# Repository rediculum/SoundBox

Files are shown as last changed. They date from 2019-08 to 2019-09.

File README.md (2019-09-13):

# SoundBox
Sound box like a board to launch samples stored as 8bit full-rate (32000) mono WAV files named from 1.WAV to 8.WAV (16.WAV) on a SD card with arcade buttons using a multiplexer
## Pinout
### SD Card > Arduino pinout:
```
SCK  (5) -> Pin 13 must be!
CS (1)   -> Pin 10 (Chip select)
MOSI (2) -> Pin 11 must be!
MISO (7) -> Pin 12 must be!
```
### Speaker -> Arduino pinout:
```
Speaker (sound) -> Pin 9 and GND
```
### Multiplexer > Arduino pinout:
```
S0 -> Pin 2
S1 -> Pin 3
S2 -> Pin 4
S3 -> Pin 5 if you have a CD74HC4067 mux and provide 16 arcade buttons
SIG (Z or A) -> Pin A0
SIG (Z or A) -> Pin 6 if you have a 2nd mux for 5V luminated buttons
```
### Multiplexer -> Arcade buttons / leds:
```
A0 -> Button 1
..
A7 -> Button 8
..
A15 -> Button 16
```
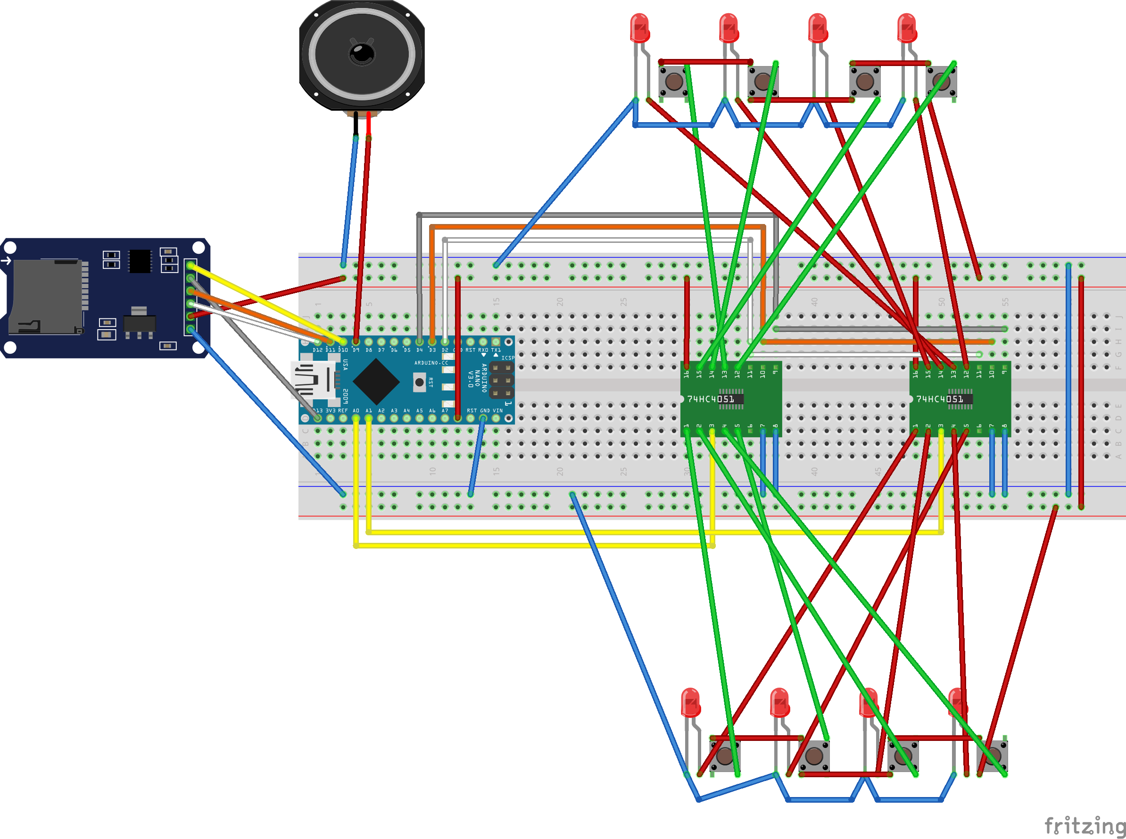
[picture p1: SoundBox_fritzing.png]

## References and used libraries
TMRpcm library for audio playback from SD card
https://github.com/TMRh20/TMRpcm or install it from Arduino IDE Lib Manager

How to deal with mux and demux
https://learn.sparkfun.com/tutorials/multiplexer-breakout-hookup-guide/all

## Convert audio to WAV with sox
This sox command will convert an MP3 file into 8bit 32k rate mono wave file.
```
sox audiofile.mp3 --norm -b8 -r32000 -c1 1.WAV
```
You may install the *libsox-fmt-mp3* package to support MP3 convertion.

## Enclosure printing
Refer to Thingiverse.com for STL download or use the Customizer to make your own case
https://www.thingiverse.com/thing:3830885
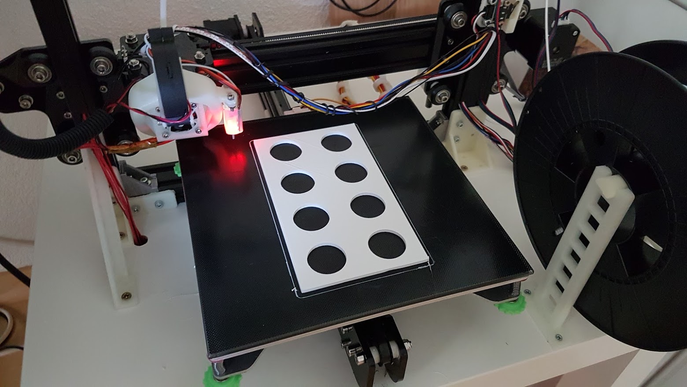
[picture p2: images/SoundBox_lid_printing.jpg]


## Pictures
### Prototype connection with jumper wires and bread board
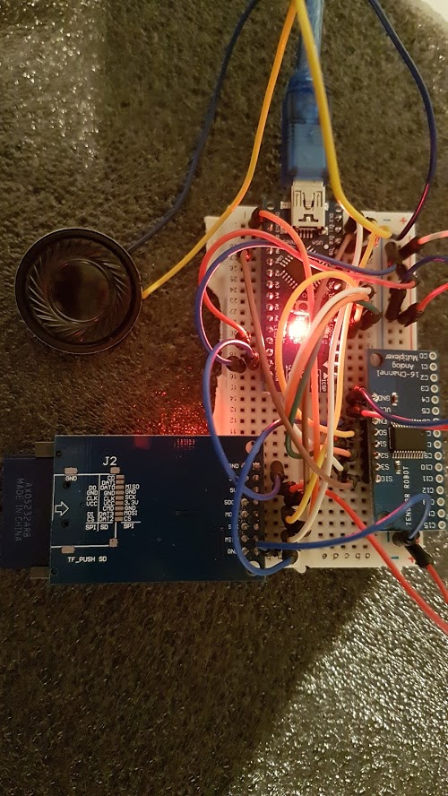
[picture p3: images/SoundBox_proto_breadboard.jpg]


### Final assembly with dupont cables and soldered wires
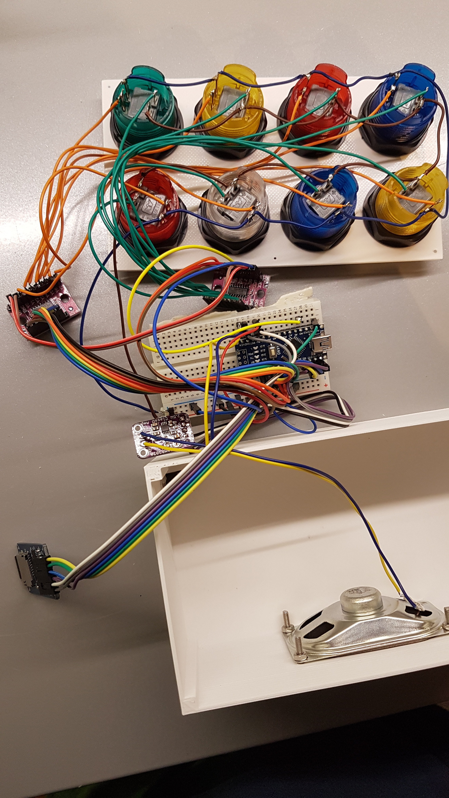
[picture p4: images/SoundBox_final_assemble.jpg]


### Demo video
(https://youtu.be/nFHPtpK2-tA)

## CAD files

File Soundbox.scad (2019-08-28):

Render = "entire"; // [body:Case,lid:Lid,entire:Entire]

screw_cones = true; // [true:Yes,false:No]
wall_thickness=1.5;
pillar_thickness_factor=4;
lid_thickness=3;
floor_thickness=8;
wall_height=70;
wall_width=90;
wall_length=160;
button_diameter=28; // [28:M28,24:M24]
buttons_per_row=4;
button_rows=2;

buttonSpace=wall_length/buttons_per_row;

module case() {
    translate([0,0,0])
        cube([wall_width,wall_thickness,wall_height]);
        cube([wall_thickness,wall_length,wall_height]);
        cube([wall_width,wall_length,floor_thickness]); // floor

    translate([0,wall_length,0])
        cube([wall_width,wall_thickness,wall_height]);

    translate([wall_width,0,0])
        cube([wall_thickness,wall_length+wall_thickness,wall_height]);

    // Pillars
        translate([wall_thickness,wall_thickness,0])
            cube([wall_thickness*pillar_thickness_factor,wall_thickness*pillar_thickness_factor,wall_height]);
        translate([wall_width-pillar_thickness_factor-wall_thickness,wall_thickness,0])
            cube([wall_thickness*pillar_thickness_factor,wall_thickness*pillar_thickness_factor,wall_height]);
        translate([wall_thickness,wall_length/2-pillar_thickness_factor/2,0])
            cube([wall_thickness*pillar_thickness_factor,wall_thickness*pillar_thickness_factor,wall_height]);
        translate([wall_width-pillar_thickness_factor-wall_thickness,wall_length/2-pillar_thickness_factor/2,0])
            cube([wall_thickness*pillar_thickness_factor,wall_thickness*pillar_thickness_factor,wall_height]);
        translate([wall_thickness,wall_length-pillar_thickness_factor-wall_thickness,0])
            cube([wall_thickness*pillar_thickness_factor,wall_thickness*pillar_thickness_factor,wall_height]);
        translate([wall_width-pillar_thickness_factor-wall_thickness,wall_length-pillar_thickness_factor-wall_thickness,0])
            cube([wall_thickness*pillar_thickness_factor,wall_thickness*pillar_thickness_factor,wall_height]);


};

module lid() {
    difference() {
        translate([0,0,wall_height]) cube([wall_width+wall_thickness,wall_length+wall_thickness,lid_thickness]); // lid
        for ( r = [1:2:3] ) {        
            for ( h = [0:buttons_per_row-1] ) {
               translate ([wall_width/4*r+wall_thickness/2,buttonSpace*h+wall_thickness/2+buttonSpace/2,wall_height]) cylinder(lid_thickness*2, button_diameter/2,button_diameter/2);
            };
        };
        // Screw cones
        if (screw_cones) {
            translate([wall_thickness+pillar_thickness_factor/2,wall_thickness+pillar_thickness_factor/2,wall_height])
                cylinder($fn=20,pillar_thickness_factor,pillar_thickness_factor/6,lid_thickness);
            translate([wall_width-pillar_thickness_factor+pillar_thickness_factor/2,wall_thickness+pillar_thickness_factor/2,wall_height])
                cylinder($fn=20,pillar_thickness_factor,pillar_thickness_factor/6,lid_thickness);
            translate([wall_thickness+pillar_thickness_factor/2,wall_length/2,wall_height])
                cylinder($fn=20,pillar_thickness_factor,pillar_thickness_factor/6,lid_thickness);
            translate([wall_width-pillar_thickness_factor/2,wall_length/2+wall_thickness,wall_height])
                cylinder($fn=20,pillar_thickness_factor,pillar_thickness_factor/6,lid_thickness);
            translate([wall_thickness+pillar_thickness_factor/2,wall_length-pillar_thickness_factor/2,wall_height])
                cylinder($fn=20,pillar_thickness_factor,pillar_thickness_factor/6,lid_thickness);
            translate([wall_width-pillar_thickness_factor/2,wall_length-pillar_thickness_factor/2,wall_height])
                cylinder($fn=20,pillar_thickness_factor,pillar_thickness_factor/6,lid_thickness);
        };
    };
};
 
if ((Render=="body") || (Render=="entire"))  case();
if ((Render=="lid") || (Render=="entire")) lid();

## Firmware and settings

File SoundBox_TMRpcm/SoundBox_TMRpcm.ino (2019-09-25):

/*
===========================================================================
Sound Box 1.0 TMRpcm version
by ReDiculum (Aug - Sep 2019)
-------------------------------
Sound box like a board to launch samples stored as 
8bit full-rate (62500) mono WAV files named from
01.WAV to 08.WAV, 11.WAV to 18.WAV, 21.WAV to 28.WAV, ... 
on a SD card with arcade buttons using a multiplexer

https://github.com/rediculum/SoundBox

SD Card > Arduino pinout:

SCK  (5) -> Pin 13 must be!
CS (1)   -> Pin 10 (Chip select)
MOSI (2) -> Pin 11 must be!
MISO (7) -> Pin 12 must be!

Speaker (sound) -> Pin 9 and GND

Potentiometer -> Pin A1

Multiplexer > Arduino pinout:
S0 -> Pin 2
S1 -> Pin 3
S2 -> Pin 4
SIG -> Pin A0 // Z of the button switch mux
SIG -> Pin 6 // Z of the button led mux if you use 5V luminated buttons

===========================================================================
References:

TMRpcm library for audio playback from SD card
https://github.com/TMRh20/TMRpcm or install it from Arduino IDE Lib Manager

How to deal with mux and demux
https://learn.sparkfun.com/tutorials/multiplexer-breakout-hookup-guide/all

===========================================================================
=== Begin of CONFIGURATION ===
*/

// Pin assignment
#define SPEAKER_PIN 9
#define SD_CHIPSELECT_PIN 10
#define Z_SWITCH_PIN A0
#define Z_LED_PIN 6
#define BUTTONS 8 // Amount of acrade buttons
#define POTI A1

// Define your S-pins from your multiplexer here. 
const byte selectPins[] = {2, 3, 4};

// Do you use a 2nd multiplexer for the button LEDs?
bool led = false;
bool fade = true; // only works with analog Z on mux

/*
===========================================================================
=== End of CONFIGURATION ===
*/

#include <SD.h>
#include <TMRpcm.h>
#include <SPI.h>

byte s_pins = sizeof(selectPins);
byte brightness = 0;
bool increment = true;

TMRpcm SdPlay;
  
void setup() {
  Serial.begin(9600); // Set console to 57600 baud
  Serial.println("=== SoundBox based on TMRpcm ===");      

  for (int i=0; i<s_pins; i++)
  {
    pinMode(selectPins[i], OUTPUT);
    digitalWrite(selectPins[i], HIGH);
  }
  
  if (led) {
    pinMode(Z_LED_PIN, OUTPUT);

    for (byte button=0; button<BUTTONS; button++)  {
      for (byte i=0; i<s_pins; i++) {
        digitalWrite(selectPins[i], button & (1<<i)?HIGH:LOW);
      }
      digitalWrite(Z_LED_PIN, HIGH);
      delay(100);
      digitalWrite(Z_LED_PIN, LOW);
    }
  }

  // Set Chip Select Pin
  SdPlay.speakerPin = SPEAKER_PIN;
  // Initialize SD Card with library SimpleSDAudio
  if (!SD.begin(SD_CHIPSELECT_PIN)) {
    tone(SPEAKER_PIN,100); delay(250); noTone(SPEAKER_PIN); delay(400);
    tone(SPEAKER_PIN,80); delay(600); noTone(SPEAKER_PIN);
    Serial.println("Error initializing SD Card");
  } else {
    Serial.println("SD Card initialized");
  }
}

void loop(void) { 
  // Read the poti value to get the decimal offset of the filename
  byte potival = map(analogRead(POTI),0,1023,0,4);
  // Loop through all eight pins holding an arcade button and set S pins accordingly.
  for (byte button=0; button<BUTTONS; button++) {
    for (byte i=0; i<s_pins; i++) {
      digitalWrite(selectPins[i], button & (1<<i)?HIGH:LOW);
    }
    // read Z and reduce value
    byte launch = map(analogRead(Z_SWITCH_PIN),0,1010,0,1);
    if (launch) {
      /* define a char array with an index size of 6 and convert
      integer "button" to char "track" using utoa() function
      http://www.nongnu.org/avr-libc/user-manual/group__avr__stdlib.html 
      */
      char track[6]; 
      utoa(button+1,track,10);
      // Do the same for the poti value
      char filename[6];
      utoa(potival,filename,10);
      // Append the offset and suffix to the char array
      strcat(filename, track);
      strcat(filename, ".WAV");
      
      Serial.print("Playing..."); Serial.println(filename);
      SdPlay.play(filename);
 
      while(SdPlay.isPlaying()) {
        if (led) {
          if (fade) {
            analogWrite(Z_LED_PIN, brightness);
            (brightness == 0) ? increment = true : true;
            (brightness == 255) ? increment = false : true;
            (increment) ? brightness++ : brightness--;
            delayMicroseconds(300);
          } else {
            (digitalRead(Z_LED_PIN) == "LOW") ? digitalWrite(Z_LED_PIN, HIGH) : digitalWrite(Z_LED_PIN, LOW);
            delay(200);
          }
        }
      }
   
      if (led) {
        (fade) ? analogWrite(Z_LED_PIN, 0): digitalWrite(Z_LED_PIN, LOW);
      }
    delay(20);
    }
  }
}

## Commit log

2019-08-19 :newspaper: Soundbox case
    [Soundbox.scad]
2019-08-19 :newspaper: Arduino Sketch
2019-08-19 :truck: move arduino project in own folder
2019-08-19 Update SoundBox_SimpleSDAudio.ino
    :pencil2: pin array ouside setup(). correct selectMuxPin argument"
2019-08-19 :pencil2: remove CRNL and move buttonSpace out of module
    [Soundbox.scad]
2019-08-19 :sparkles: add inner corners in case
    [Soundbox.scad]
2019-08-20 :sparkles: support luminated buttons
2019-08-21 :fire: remove unnecessary println
2019-08-21 Revert ":fire: remove unnecessary println"
    This reverts commit 841d59ae56d93dde273e0fd32508cf58e78f87fa.
    [SoundBox_TMRpcm.ino]
2019-08-23 :newspaper: new Fritzing drawings
    [SoundBox.fzz]
2019-08-24 :pencil: reduce wall size
    [Soundbox.scad]
2019-08-25 :pencil: increase thickness of lid
    [Soundbox.scad]
2019-08-26 :newspaper: lid printing
2019-08-27 :books: add mux->buttons pinout
2019-08-28 :sparkles: add screw cones for lid
    [Soundbox.scad]
2019-09-13 :pencil: change LED pin to PWN
2019-09-13 :bug: led check on setup after set pinMode
    [SoundBox_TMRpcm.ino]
2019-09-13 :newspaper: final assembly pic
2019-09-13 :pencil: :books: change LED pin to PWN
2019-09-25 :pencil: :sparkles: get rid of 16 chan mux. add poti for track offset.
